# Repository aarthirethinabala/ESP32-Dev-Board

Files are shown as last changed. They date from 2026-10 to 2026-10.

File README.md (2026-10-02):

# ESP32 Development Board
Custom ESP32 development board designed and routed in KiCad, including schematic design, component footprint assignment, PCB layout, routing and 3D visualization.

## Project Status
Completed

## Overview
This project is a custom ESP32 development board based on the ESP32-WROOM module.
The board was designed from the schematic stage through PCB layout and routing, including power regulation, USB-to-UART communication, boot/reset controls, GPIO headers, and supporting components.

## Tools Used
- KiCad
- PCB Editor
- Schematic Editor
- 3D Viewer

## Board Features
- ESP32-WROOM module
- USB-to-UART interface
- 5V to 3.3V voltage regulation
- Boot and reset controls
- GPIO headers
- Status LED
- Two-layer PCB
- Ground copper zones

## Design Process
- Studied the reference ESP32 board circuitry
- Converted the reference into hierarchical KiCad sheets
- Assigned footprints
- Designed component placement independently
- Routed the PCB manually
- Added vias and layer changes where required
- Checked the design with ERC/DRC
- Corrected connectivity and layout issues

## Project Images
### Root Schematic
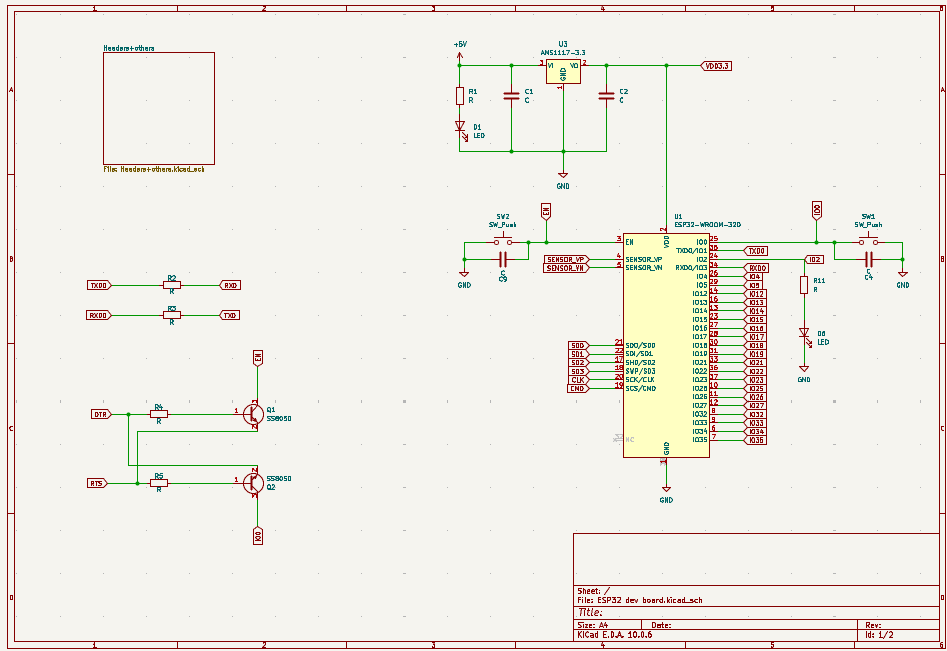
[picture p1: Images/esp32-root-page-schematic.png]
Root Schematic


### Page 2 Schematic
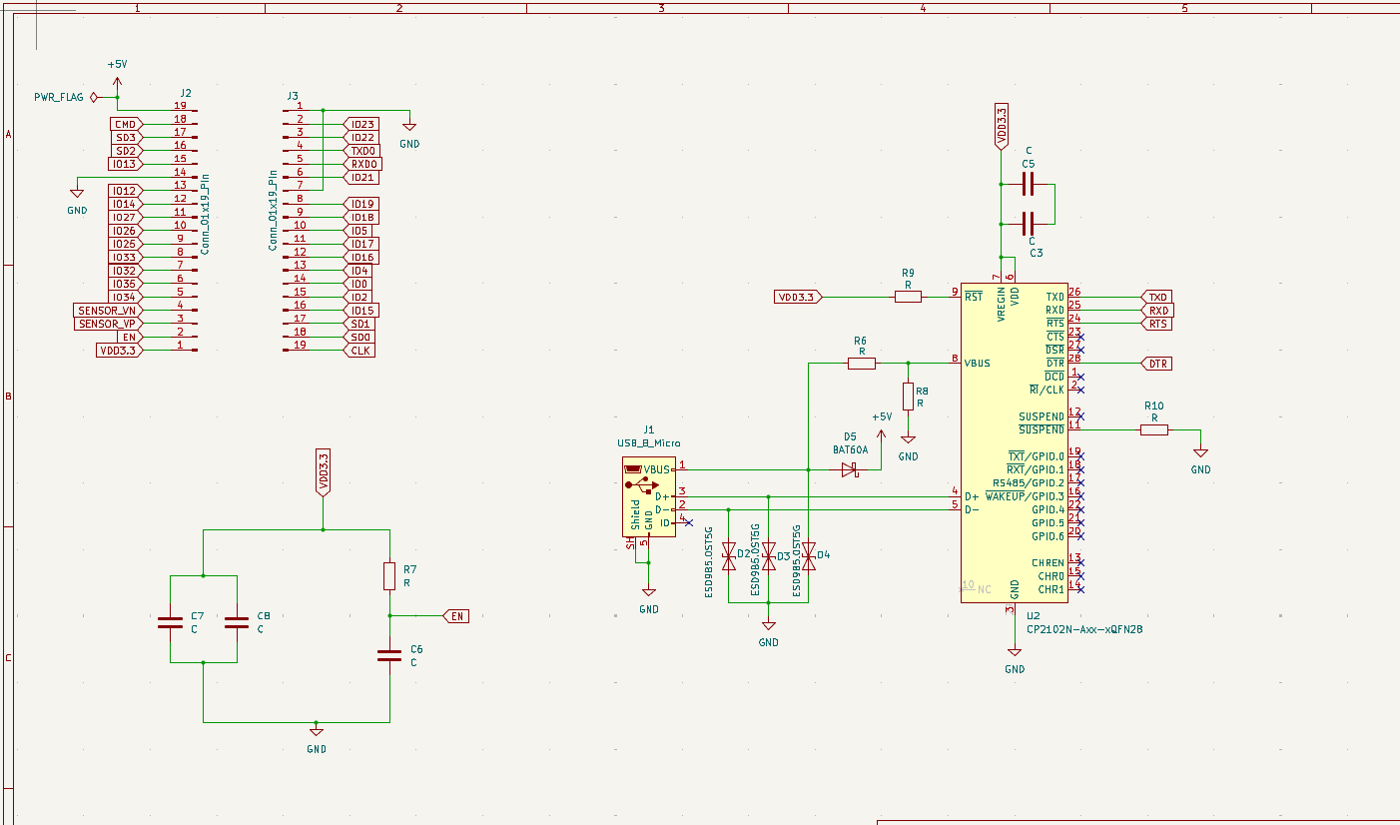
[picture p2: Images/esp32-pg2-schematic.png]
Page 2 Schematic


### PCB Layout
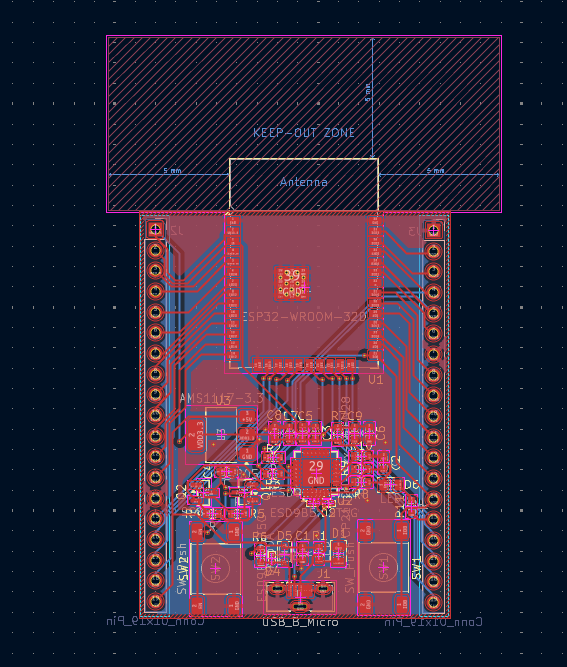
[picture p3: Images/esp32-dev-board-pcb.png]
PCB Layout


### 3D Front View 
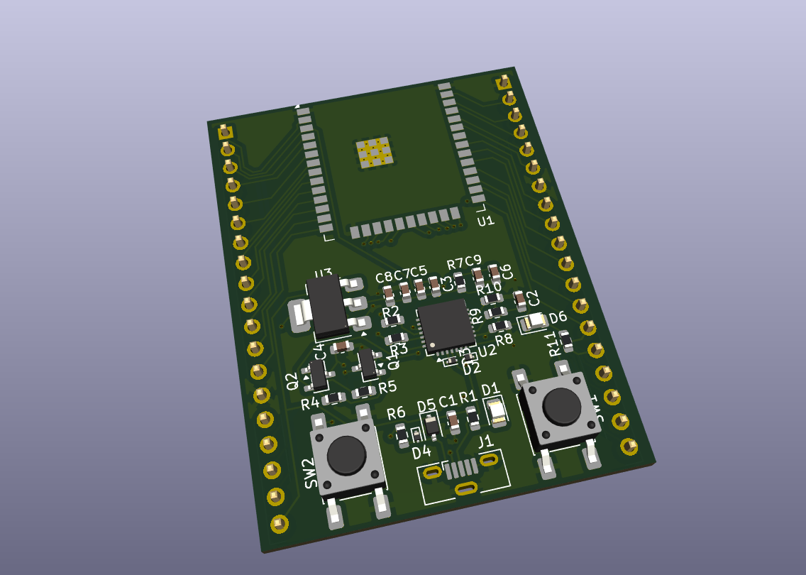
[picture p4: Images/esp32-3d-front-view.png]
3D Front View


### 3D Back View
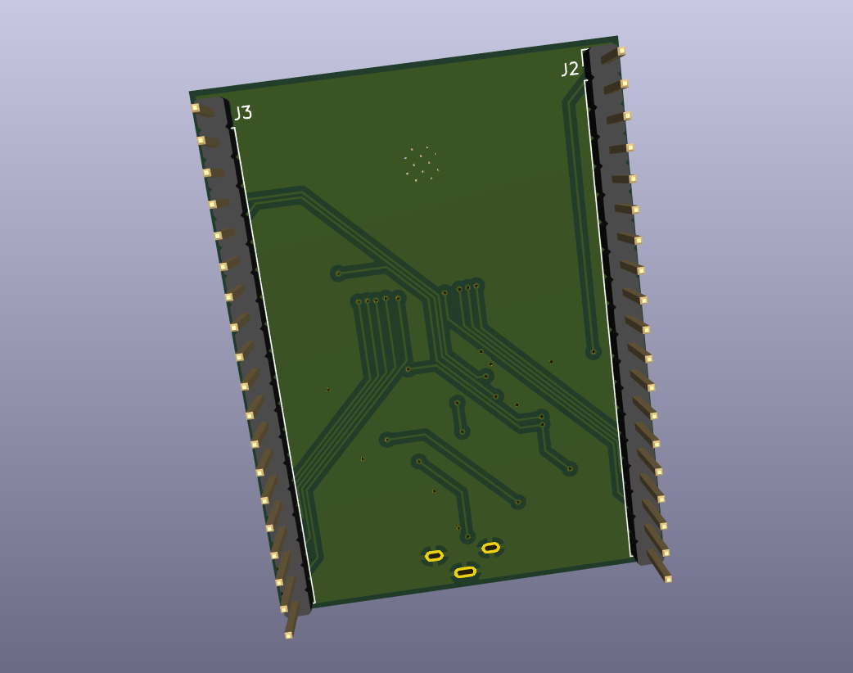
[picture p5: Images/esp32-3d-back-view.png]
3D Back View


## What I Learned
- Hierarchical schematic organization
- ESP32 development-board architecture
- Footprint selection
- Two-layer PCB design
- Via usage and layer transitions
- Ground planes/zones
- DRC troubleshooting
- Independent component placement and routing

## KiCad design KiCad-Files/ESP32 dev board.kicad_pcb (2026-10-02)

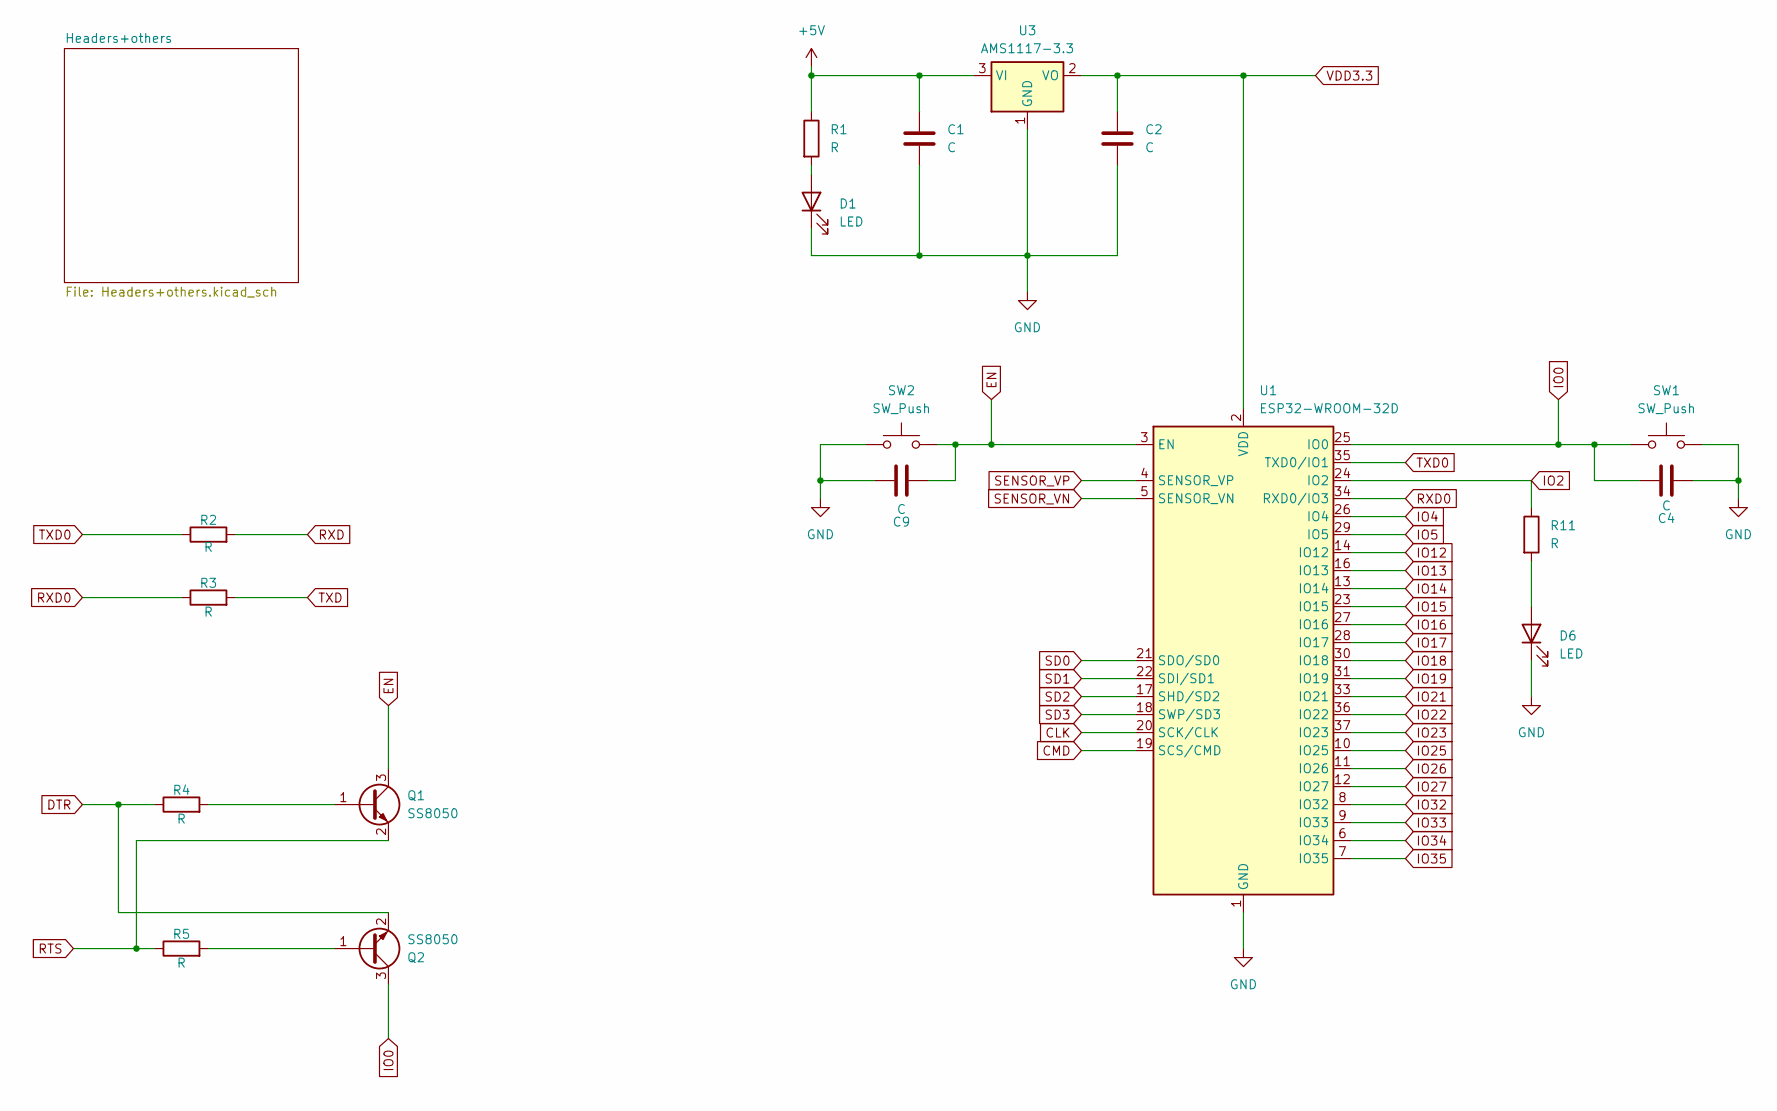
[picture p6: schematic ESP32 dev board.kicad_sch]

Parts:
C1, C2, C4, C9: C; C_0603_1608Metric
D1, D6: LED; LED_0805_2012Metric
Q1, Q2: SS8050; SOT-23
R1, R2, R3, R4, R5, R11: R; R_0603_1608Metric
SW1, SW2: SW_Push; SW_Push_1P1T_NO_E-Switch_TL3301NxxxxxG
U1: ESP32-WROOM-32D
U3: AMS1117-3.3; SOT-223-3_TabPin2

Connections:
+5V: C1.1, R1.1, U3.3 (VI); also elsewhere on the board
CLK: U1.20 (SCK/CLK); also elsewhere on the board
CMD: U1.19 (SCS/CMD); also elsewhere on the board
DTR: Q2.2 (E), R4.1; also elsewhere on the board
EN: C9.2, Q1.3 (C), SW2.2, U1.3 (EN); also elsewhere on the board
GND: C1.2, C2.2, C4.2, C9.1, D1.1 (K), D6.1 (K), SW1.2, SW2.1, U1.1 (GND), U1.15 (GND), U1.38 (GND), U1.39 (GND), U3.1 (GND); also elsewhere on the board
IO0: C4.1, Q2.3 (C), SW1.1, U1.25 (IO0); also elsewhere on the board
IO2: R11.1, U1.24 (IO2); also elsewhere on the board
IO4: U1.26 (IO4); also elsewhere on the board
IO5: U1.29 (IO5); also elsewhere on the board
IO12: U1.14 (IO12); also elsewhere on the board
IO13: U1.16 (IO13); also elsewhere on the board
IO14: U1.13 (IO14); also elsewhere on the board
IO15: U1.23 (IO15); also elsewhere on the board
IO16: U1.27 (IO16); also elsewhere on the board
IO17: U1.28 (IO17); also elsewhere on the board
IO18: U1.30 (IO18); also elsewhere on the board
IO19: U1.31 (IO19); also elsewhere on the board
IO21: U1.33 (IO21); also elsewhere on the board
IO22: U1.36 (IO22); also elsewhere on the board
IO23: U1.37 (IO23); also elsewhere on the board
IO25: U1.10 (IO25); also elsewhere on the board
IO26: U1.11 (IO26); also elsewhere on the board
IO27: U1.12 (IO27); also elsewhere on the board
IO32: U1.8 (IO32); also elsewhere on the board
IO33: U1.9 (IO33); also elsewhere on the board
IO34: U1.6 (IO34); also elsewhere on the board
IO35: U1.7 (IO35); also elsewhere on the board
unnamed: D1.2 (A), R1.2
unnamed: D6.2 (A), R11.2
unnamed: Q1.1 (B), R4.2
unnamed: Q2.1 (B), R5.2
RTS: Q1.2 (E), R5.1; also elsewhere on the board
RXD: R2.2; also elsewhere on the board
RXD0: R3.1, U1.34 (RXD0/IO3); also elsewhere on the board
SD0: U1.21 (SDO/SD0); also elsewhere on the board
SD1: U1.22 (SDI/SD1); also elsewhere on the board
SD2: U1.17 (SHD/SD2); also elsewhere on the board
SD3: U1.18 (SWP/SD3); also elsewhere on the board
SENSOR_VN: U1.5 (SENSOR_VN); also elsewhere on the board
SENSOR_VP: U1.4 (SENSOR_VP); also elsewhere on the board
TXD: R3.2; also elsewhere on the board
TXD0: R2.1, U1.35 (TXD0/IO1); also elsewhere on the board
VDD3.3: C2.1, U1.2 (VDD), U3.2 (VO); also elsewhere on the board

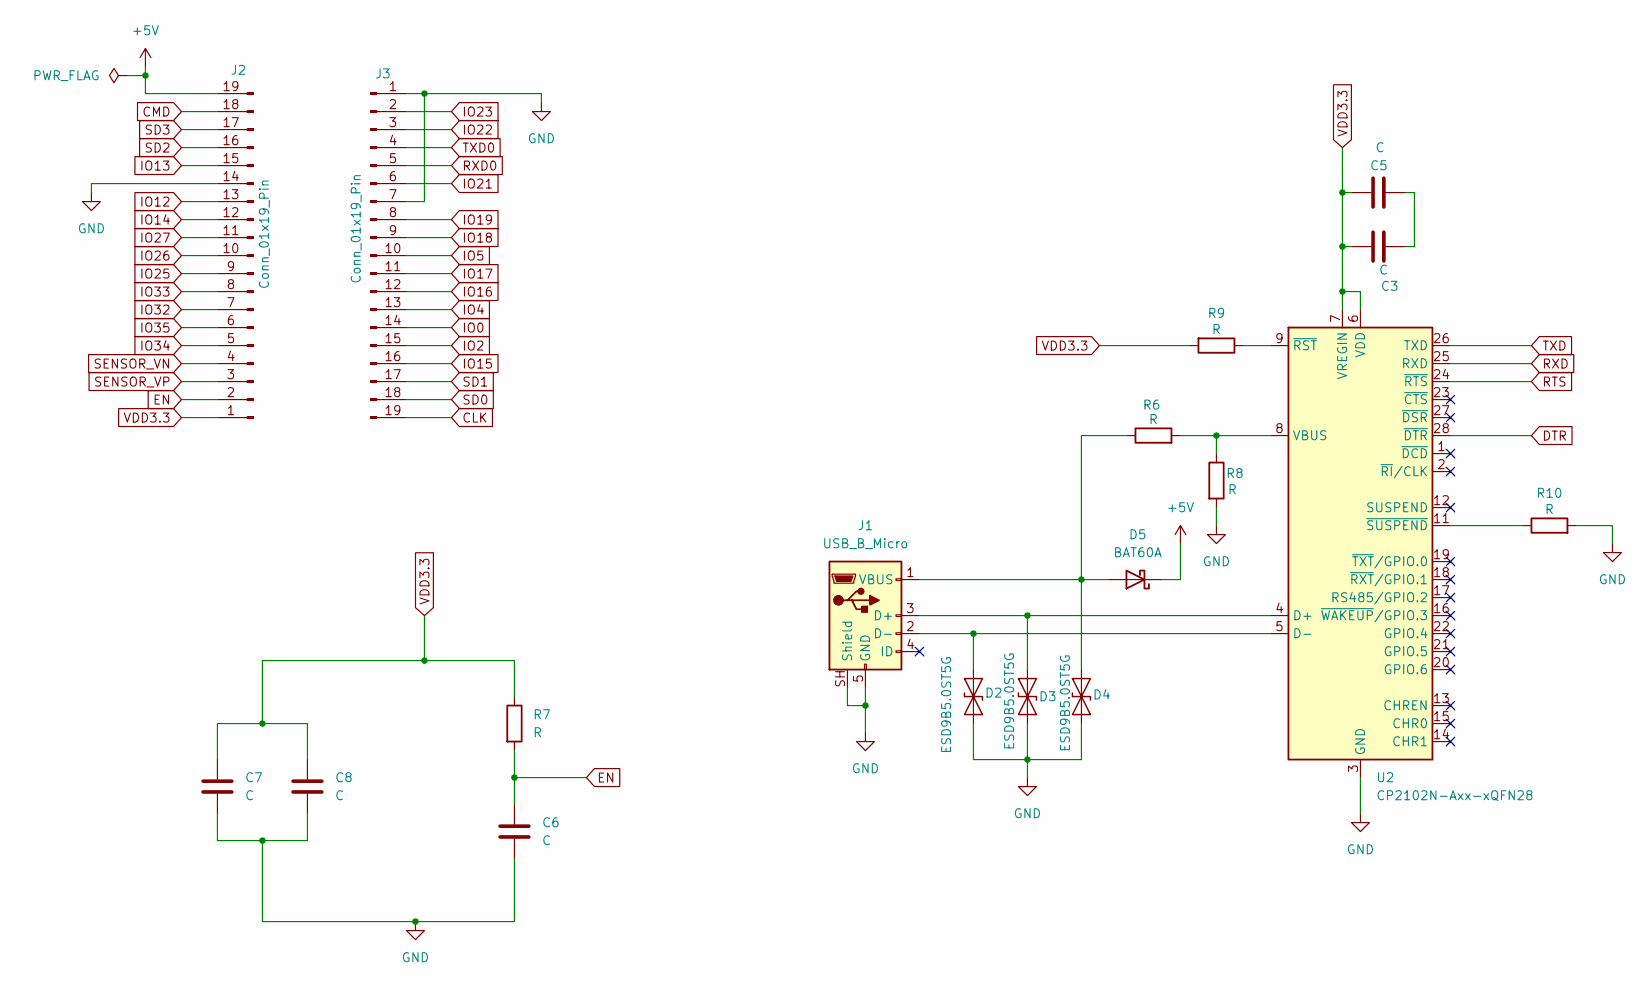
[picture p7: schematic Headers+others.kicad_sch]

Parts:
C3, C5, C6, C7, C8: C; C_0603_1608Metric
D2, D3, D4: ESD9B5.0ST5G; D_SOD-923
D5: BAT60A; D_SOD-323
J1: USB_B_Micro; USB_Micro-B_Molex-105133-0001
J2, J3: Conn_01x19_Pin; PinHeader_1x19_P2.54mm_Vertical
R6, R7, R8, R9, R10: R; R_0603_1608Metric
U2: CP2102N-Axx-xQFN28; QFN-28-1EP_5x5mm_P0.5mm_EP3.35x3.35mm

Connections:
+5V: D5.1 (K), J2.19; also elsewhere on the board
CLK: J3.19; also elsewhere on the board
CMD: J2.18; also elsewhere on the board
DTR: U2.28 (~DTR); also elsewhere on the board
EN: C6.1, J2.2, R7.2; also elsewhere on the board
GND: C6.2, C7.2, C8.2, D2.1 (A1), D3.1 (A1), D4.1 (A1), J1.5 (GND), J1.SH (Shield), J2.14, J3.1, J3.7, R8.2, R10.2, U2.3 (GND), U2.29 (GND); also elsewhere on the board
IO0: J3.14; also elsewhere on the board
IO2: J3.15; also elsewhere on the board
IO4: J3.13; also elsewhere on the board
IO5: J3.10; also elsewhere on the board
IO12: J2.13; also elsewhere on the board
IO13: J2.15; also elsewhere on the board
IO14: J2.12; also elsewhere on the board
IO15: J3.16; also elsewhere on the board
IO16: J3.12; also elsewhere on the board
IO17: J3.11; also elsewhere on the board
IO18: J3.9; also elsewhere on the board
IO19: J3.8; also elsewhere on the board
IO21: J3.6; also elsewhere on the board
IO22: J3.3; also elsewhere on the board
IO23: J3.2; also elsewhere on the board
IO25: J2.9; also elsewhere on the board
IO26: J2.10; also elsewhere on the board
IO27: J2.11; also elsewhere on the board
IO32: J2.7; also elsewhere on the board
IO33: J2.8; also elsewhere on the board
IO34: J2.5; also elsewhere on the board
IO35: J2.6; also elsewhere on the board
unnamed: C3.1, C5.1
unnamed: D2.2 (A2), J1.2 (D-), U2.5 (D-)
unnamed: D3.2 (A2), J1.3 (D+), U2.4 (D+)
unnamed: D4.2 (A2), D5.2 (A), J1.1 (VBUS), R6.1
unnamed: R6.2, R8.1, U2.8 (VBUS)
unnamed: R9.1, U2.9 (~RST)
unnamed: R10.1, U2.11 (~SUSPEND)
RTS: U2.24 (~RTS); also elsewhere on the board
RXD: U2.25 (RXD); also elsewhere on the board
RXD0: J3.5; also elsewhere on the board
SD0: J3.18; also elsewhere on the board
SD1: J3.17; also elsewhere on the board
SD2: J2.16; also elsewhere on the board
SD3: J2.17; also elsewhere on the board
SENSOR_VN: J2.4; also elsewhere on the board
SENSOR_VP: J2.3; also elsewhere on the board
TXD: U2.26 (TXD); also elsewhere on the board
TXD0: J3.4; also elsewhere on the board
VDD3.3: C3.2, C5.2, C7.1, C8.1, J2.1, R7.1, R9.2, U2.6 (VDD), U2.7 (VREGIN); also elsewhere on the board

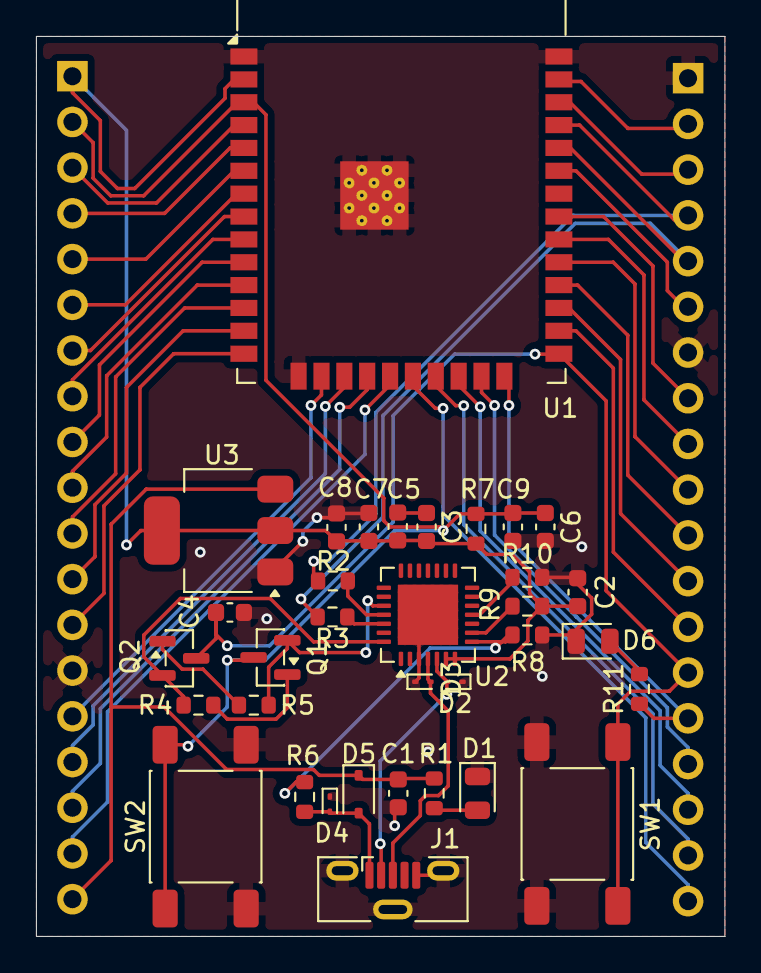
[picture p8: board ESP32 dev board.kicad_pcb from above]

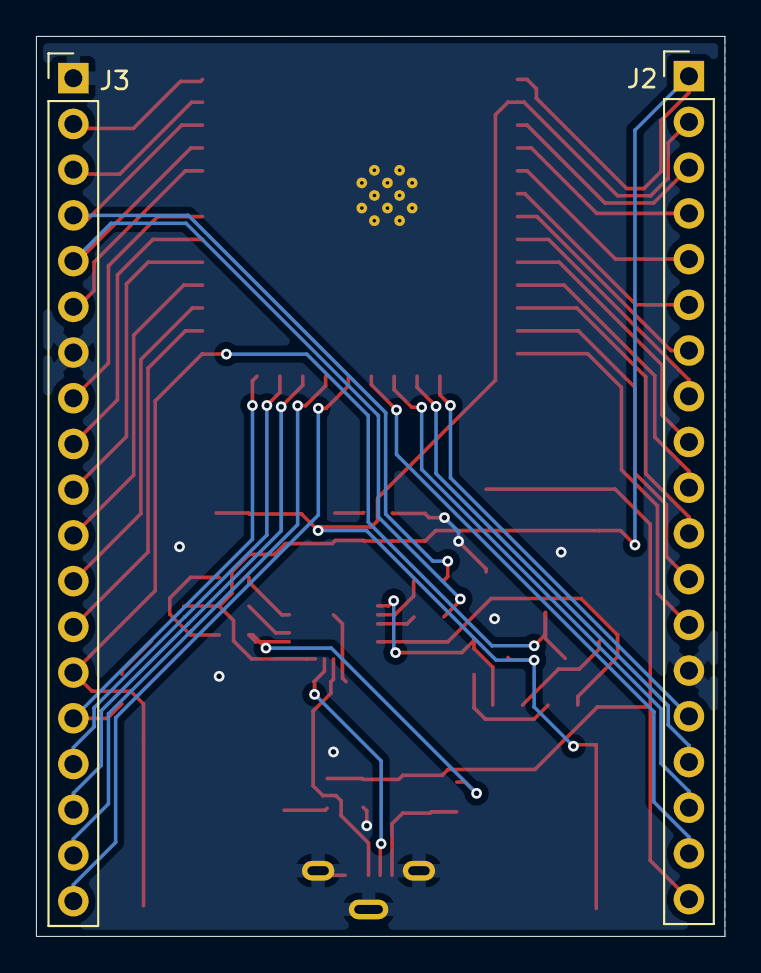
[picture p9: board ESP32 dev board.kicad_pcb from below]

Board: 2 copper layers, 38.2 x 50.0 mm, 36 parts (2 on the bottom side), 51 nets.
